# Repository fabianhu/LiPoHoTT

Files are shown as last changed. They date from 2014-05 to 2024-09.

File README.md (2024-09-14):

LiPoHoTT
========

2S to 6S LiPo monitor for HoTT telemetry.
(c) 2012-2014 Fabian Huslik

order PCBs here:
https://oshpark.com/shared_projects/f62OUvRq

Features:
Optocoupler for communication interface
2-6 Cells
2.54mm pitch connector XH or XT
emulates HoTT GAM
Calibration via full battery
Adjustable alarm levels (2)
External current monitoring possible

Future features:
2-14 in multi-chain-configuration
Configurable as HoTT GAM or EAM
Adjustable alarm delay
Bootloader for field update

This project includes hardware and firmware.

Software released under GPLv3.
Hardware "source code" = .brd & .sch realeased under GPLv3 as well.

Uses code from :

HoTT v4 telemetry for ArduCopter by Adam Majerczyk
printf library by Kustaa Nyholm / SpareTimeLabs
Interrupt UART library by Peter Fleury

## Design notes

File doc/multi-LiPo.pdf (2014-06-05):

... ?

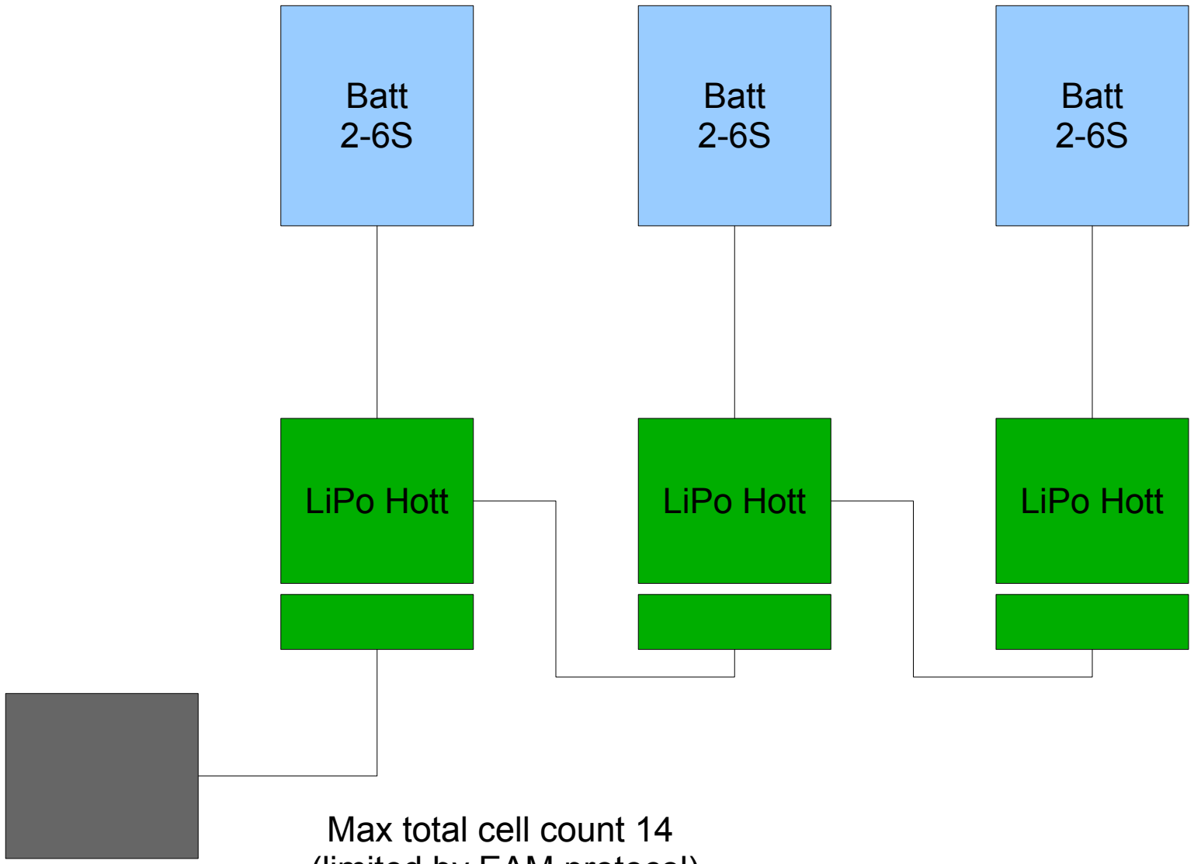
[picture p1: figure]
LiPo Hott; Batt 2-6S; Max total cell count 14

(limited by EAM protocol)

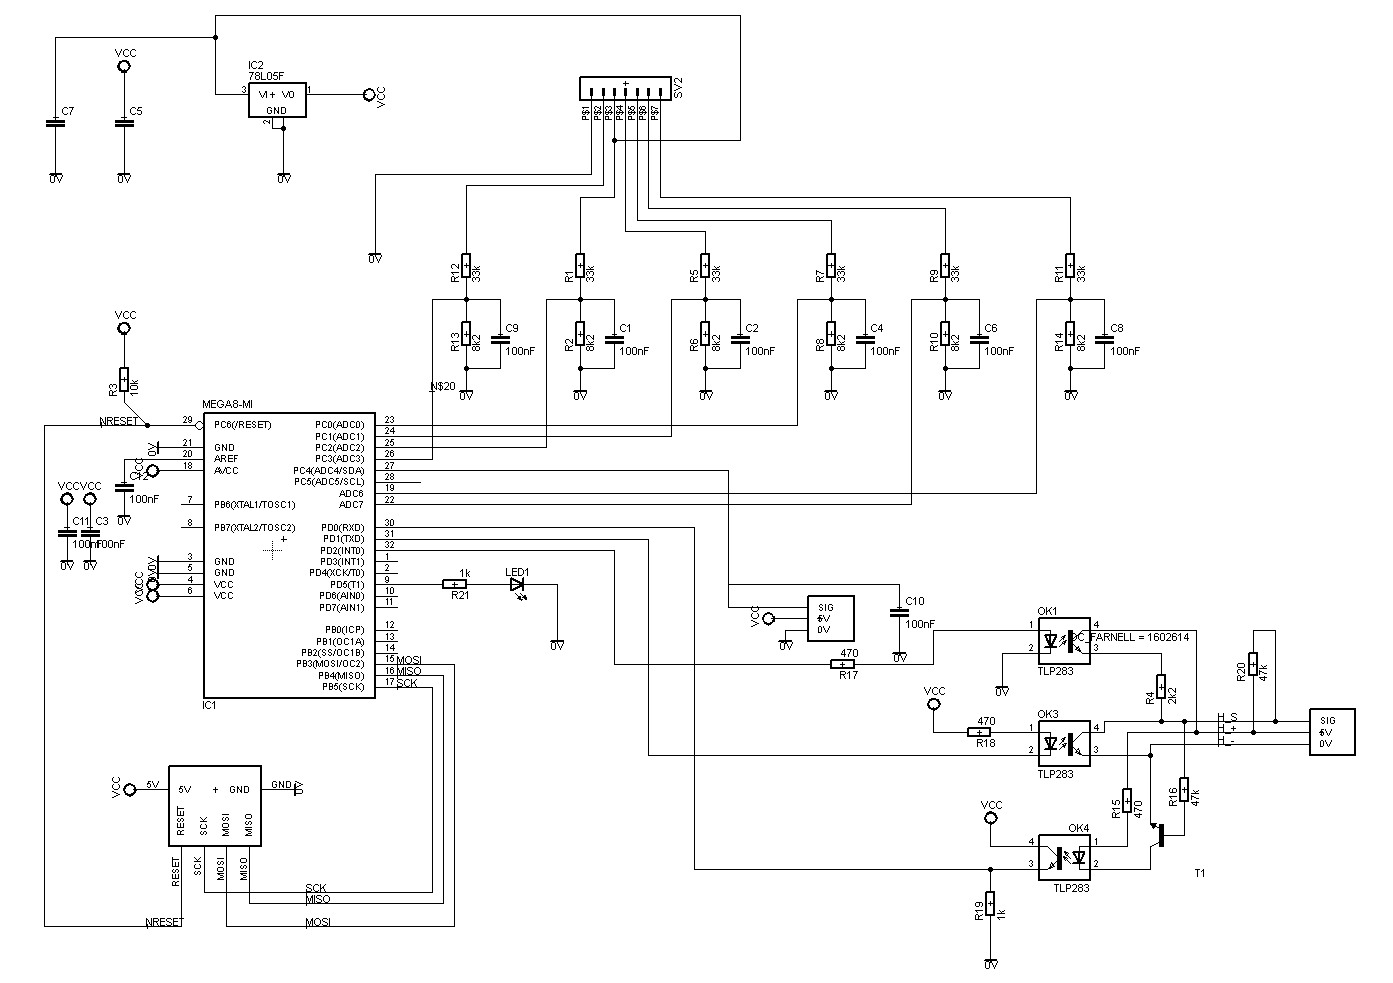
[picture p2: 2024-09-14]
doc/LiPoHott schematic.png

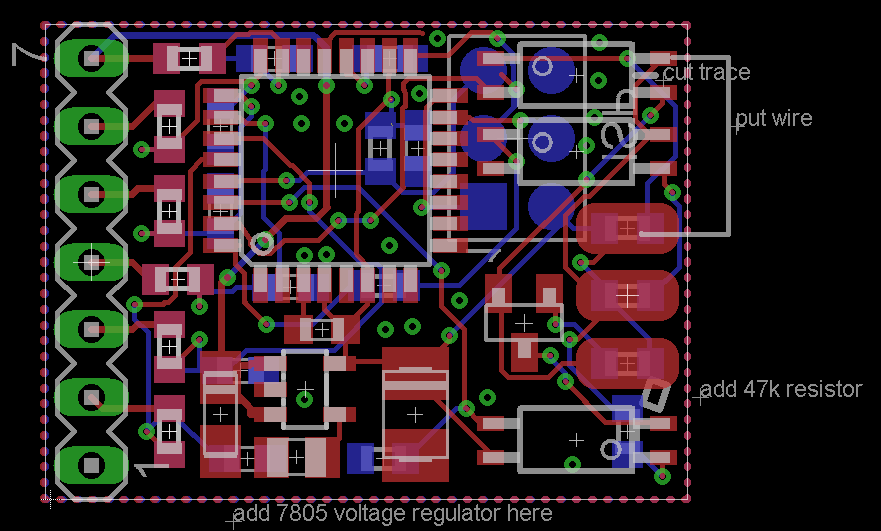
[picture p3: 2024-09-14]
doc/LiPoHoTT.png

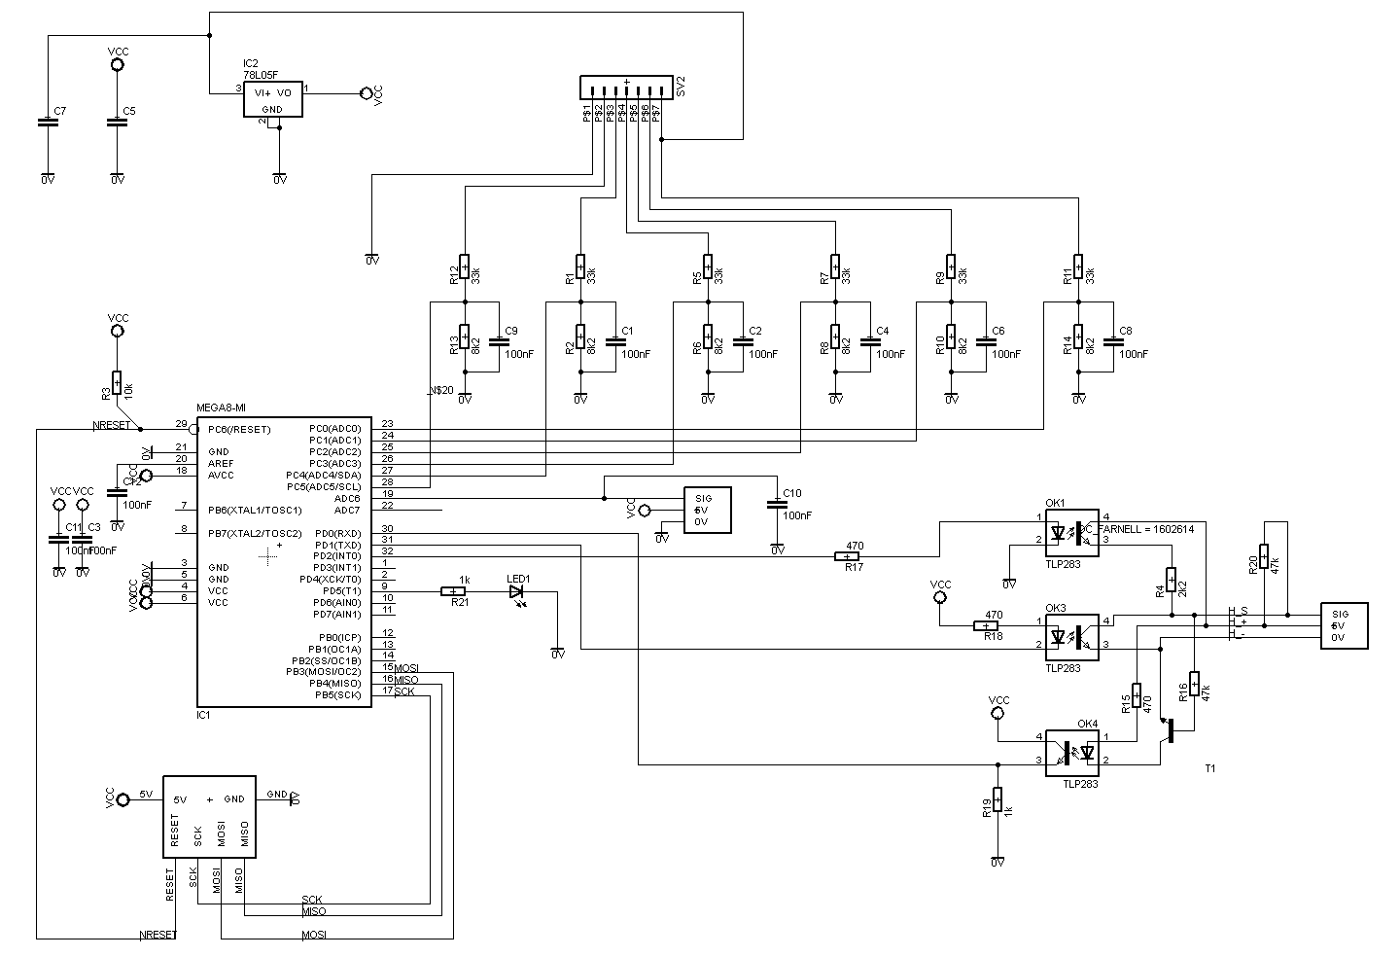
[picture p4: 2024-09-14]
doc/LiPoHott_kpl.png

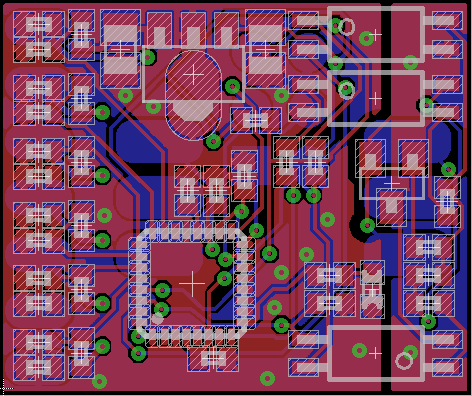
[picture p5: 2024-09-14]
doc/LiPoHoTT2.png

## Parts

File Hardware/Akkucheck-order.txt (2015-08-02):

Order list for D:/projekt/work/#Github/LiPoHoTT/Hardware/Akkucheck.sch
Exported from EAGLE with DesignLink

Anzahl	Value	Package	Ordercode	Hersteller	Herstellercode	Verfügbarkeit	Preis (ab)	Beschreibung
90	100nF	C0402	1867948	AVX	04023C104KAT2A	26032	0.0162	AVX - 04023C104KAT2A - KONDENSATOR, MLCC, X7R, 100NF, 25V, 0402
18	2u2	C0805	2320829	MULTICOMP	MC0805B225K250CT	21085	0.046	MULTICOMP - MC0805B225K250CT - KONDENSATOR, MLCC, X7R, 2.2UF, 25V, 0805
9	MEGA8-MI	MLF32	1715491	ATMEL	ATMEGA88PA-MU	1754	1.31	ATMEL - ATMEGA88PA-MU - MCU 8BIT, AVR, 8K FLASH, 32MLF
9	78L05F	SOT89	1467762	STMICROELECTRONICS	L78L05ABUTR	10209	0.142	STMICROELECTRONICS - L78L05ABUTR - SPANNUNGSREGLER,5V,SMD
18		3WIRE_CONN	unknown					
9		CHIPLED_0603	unknown					
27	TLP283	MINI-FLAT-4	1602614	AVAGO TECHNOLOGIES	ACPL-217-500E	23901	0.238	AVAGO TECHNOLOGIES - ACPL-217-500E - OPTOKOPPLER,TRANSISTOR O/P
54	33k	R0402	2331513	TE CONNECTIVITY	CRG0402F33K	21070	0.0027	TE CONNECTIVITY - CRG0402F33K - FESTWIDERSTAND, 33K, 1%, 0402
54	8k2	R0402	2331571	TE CONNECTIVITY	CRG0402F8K2	3991	0.0027	TE CONNECTIVITY - CRG0402F8K2 - FESTWIDERSTAND, 8K2, 1%, 0402
9	10k	R0402	1738864	VISHAY DRALORIC	CRCW040210K0FKEAHP	463687	0.011	VISHAY DRALORIC - CRCW040210K0FKEAHP - LEISTUNGSWIDERSTAND, 10K, 0.125W, 1%
9	2k2	R0402	2059231	PANASONIC ELECTRONIC COMPONENTS	ERJ2GEJ222X	7048	0.0020	PANASONIC ELECTRONIC COMPONENTS - ERJ2GEJ222X - WIDERSTAND, 0402, 2K2, 5%, 0.1W
27	470	R0402	2059203	PANASONIC ELECTRONIC COMPONENTS	ERJ2GEJ470X	12566	0.0021	PANASONIC ELECTRONIC COMPONENTS - ERJ2GEJ470X - WIDERSTAND, 0402, 47R, 5%, 0.1W
18	47k	R0402	2059246	PANASONIC ELECTRONIC COMPONENTS	ERJ2GEJ473X	10294	0.0020	PANASONIC ELECTRONIC COMPONENTS - ERJ2GEJ473X - WIDERSTAND, 0402, 47K, 5%, 0.1W
18	1k	R0402	2059225	PANASONIC ELECTRONIC COMPONENTS	ERJ2GEJ102X	23250	0.0020	PANASONIC ELECTRONIC COMPONENTS - ERJ2GEJ102X - WIDERSTAND, 0402, 1K, 5%, 0.1W
9		MA07-1_SMD	unknown					
9		SOT23-BEC	1081223	NXP	BC817,215	239246	0.0237	NXP - BC817,215 - TRANSISTOR, NPN, 45V, SOT-23
9	ISPSMD	ISP_SMD	unknown

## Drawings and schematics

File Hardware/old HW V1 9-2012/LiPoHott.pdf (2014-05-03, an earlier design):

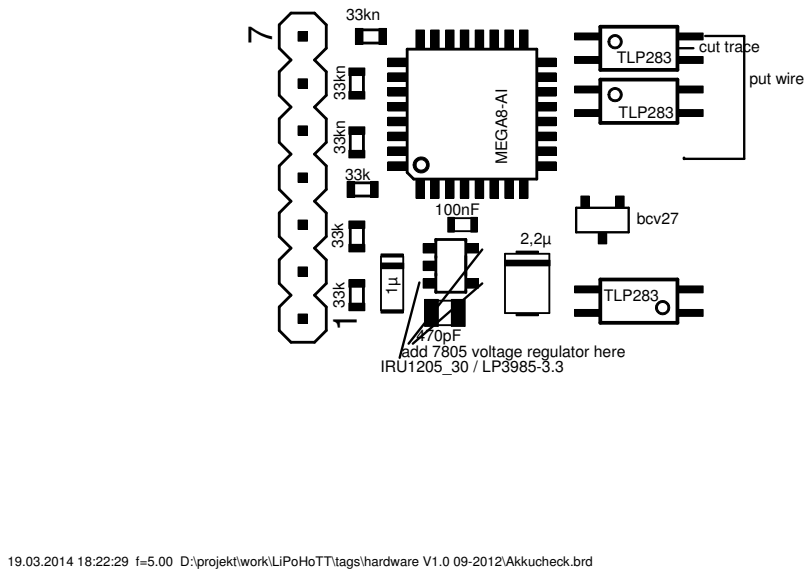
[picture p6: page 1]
7cut trace; put wire; add 7805 voltage regulator here; IRU1205_30 / LP3985-3.3; MEGA8-AI; TLP283; bcv27

19.03.2014 18:22:29 f=5.00 D:\projekt\work\LiPoHoTT\tags\hardware V1.0 09-2012\Akkucheck.brd

19.03.2014 18:23:15 f=5.00 mirrored D:\projekt\work\LiPoHoTT\tags\hardware V1.0 09-2012\Akkucheck.brd

1

# ISP

100nF

10k

10k

100nF

### 10k 100nF

10k
100nF

### 100nFn

## 10kn 10kn

### 100nFn

### 100nFn 10kn

2k2

470

33k

470

470

1k

100nF

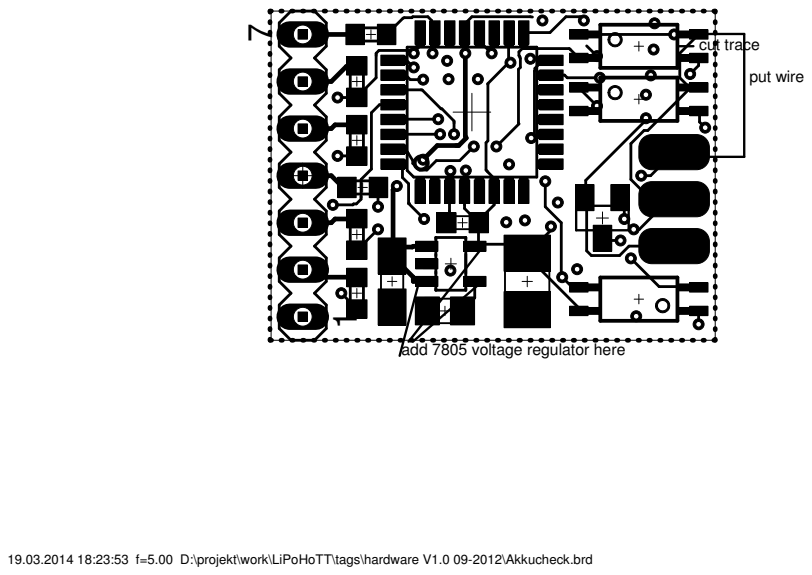
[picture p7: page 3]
7cut trace; put wire

add 7805 voltage regulator here

19.03.2014 18:23:53 f=5.00 D:\projekt\work\LiPoHoTT\tags\hardware V1.0 09-2012\Akkucheck.brd

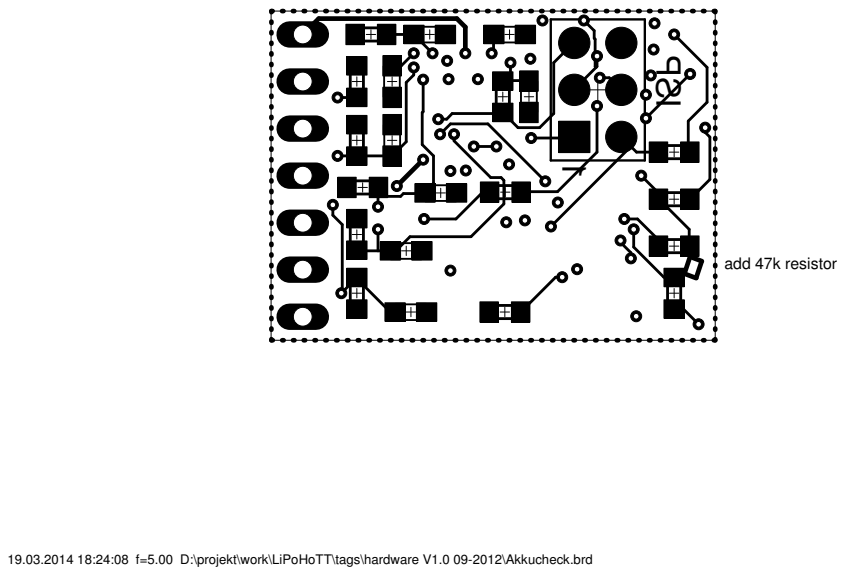
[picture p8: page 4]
add 47k resistor; ISP

19.03.2014 18:24:08 f=5.00 D:\projekt\work\LiPoHoTT\tags\hardware V1.0 09-2012\Akkucheck.brd

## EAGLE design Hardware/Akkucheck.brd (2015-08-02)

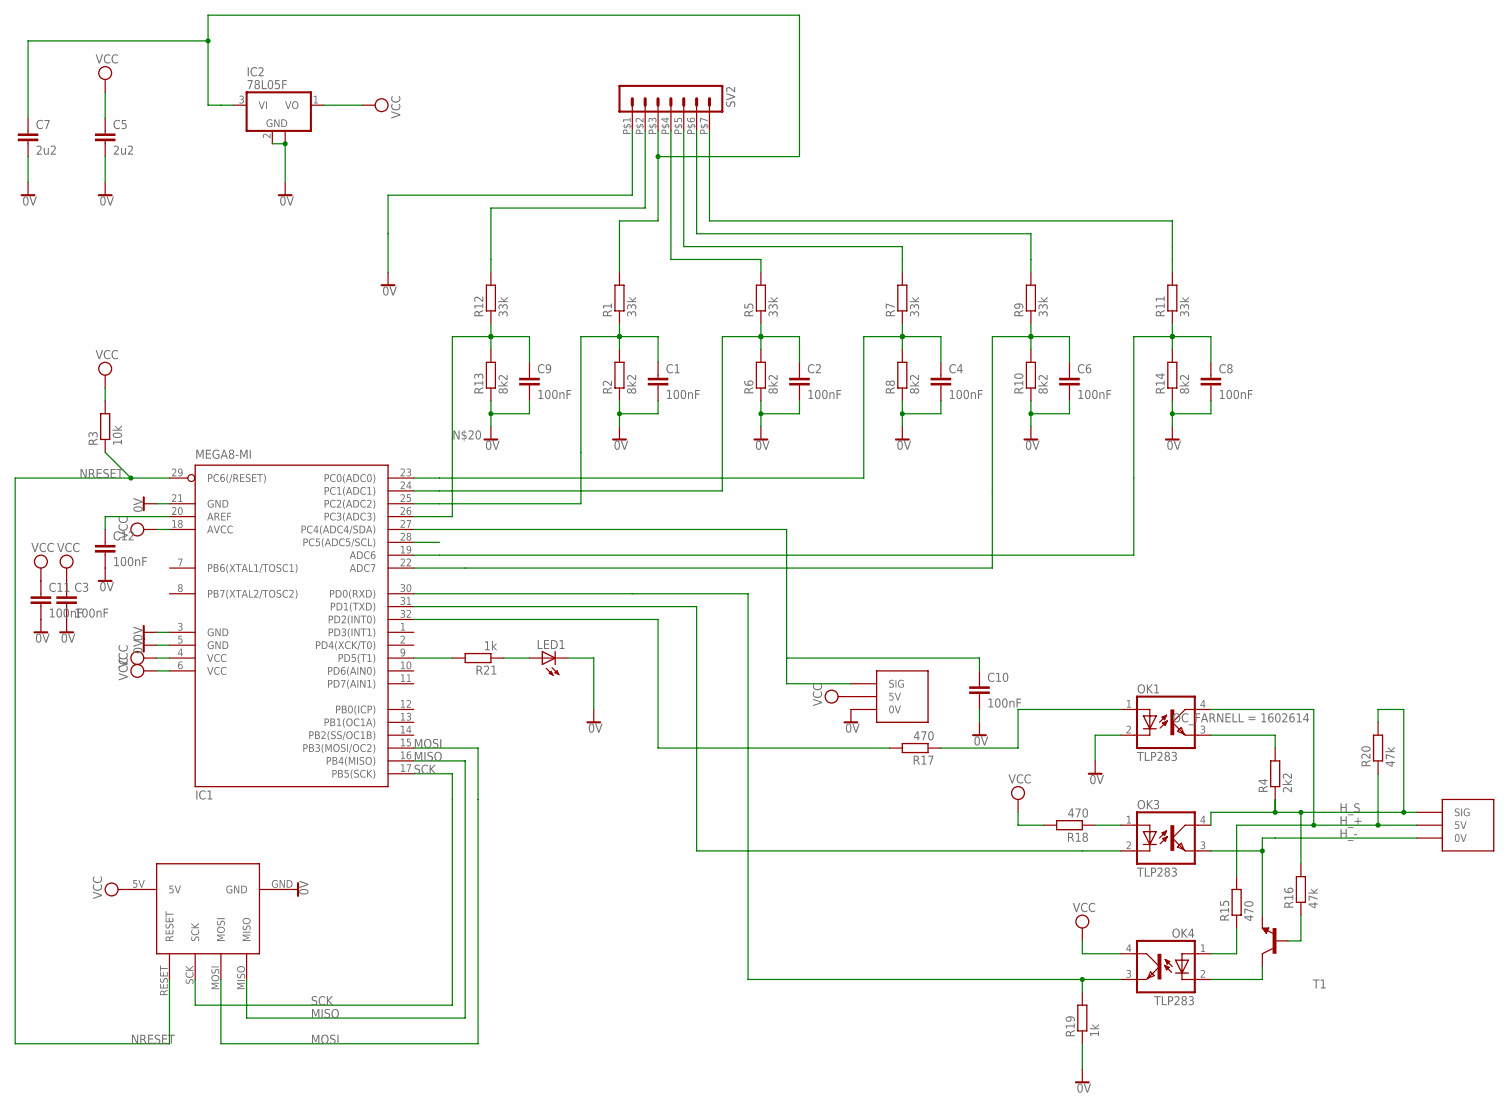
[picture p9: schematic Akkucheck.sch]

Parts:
C1, C2, C3, C4, C6, C8, C9, C10, C11, C12: 100nF; C0402; MPN 04023C104KAT2A
C5, C7: 2u2; C0805; MPN MC0805B225K250CT
IC1: MEGA8-MI; MLF32
IC2: 78L05F; SOT89; MPN L78L05ABUTR
IN1, IN3: 3-WIRE_CONNWIRE; 3WIRE_CONN
LED1: LEDCHIPLED_0603; CHIPLED_0603
OK1, OK3, OK4: TLP283; MINI-FLAT-4; MPN ACPL-217-500E
R1, R5, R7, R9, R11, R12: 33k; R0402; MPN CRG0402F33K
R2, R6, R8, R10, R13, R14: 8k2; R0402; MPN CRG0402F8K2
R3: 10k; R0402; MPN CRCW040210K0FKEAHP
R4: 2k2; R0402; MPN ERJ2GEJ222X
R15, R17, R18: 470; R0402; MPN ERJ2GEJ470X
R16, R20: 47k; R0402; MPN ERJ2GEJ473X
R19, R21: 1k; R0402; MPN ERJ2GEJ102X
SV2: MA07-1_SMD
T1: BC817-16-NPN-SOT23-BEC; SOT23-BEC; MPN BC817,215
U$1: ISPSMD; ISP_SMD

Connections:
0V: C1.2, C2.2, C3.2, C4.2, C5.2, C6.2, C7.2, C8.2, C9.2, C10.2, C11.2, C12.2, IC1.3 (GND), IC1.5 (GND), IC1.21 (GND), IC2.2 (GND), IC2.2@1 (GND), IN1.0V, LED1.C, OK1.2 (C), R2.1, R6.1, R8.1, R10.1, R13.1, R14.1, R19.1, SV2.P$1 (1), U$1.GND
H_+: IN3.5V, OK1.4 (COL), R15.2, R20.1
H_-: IN3.0V, OK3.3 (EMIT), T1.E
H_S: IN3.SIG, OK3.4 (COL), R4.1, R16.2, R20.2
MISO: IC1.16 (PB4(MISO)), U$1.MISO
MOSI: IC1.15 (PB3(MOSI/OC2)), U$1.MOSI
unnamed: R12.2, SV2.P$2 (2)
unnamed: C6.1, IC1.22 (ADC7), R9.1, R10.2
unnamed: R5.2, SV2.P$4 (4)
unnamed: R7.2, SV2.P$5 (5)
unnamed: R9.2, SV2.P$6 (6)
unnamed: C10.1, IC1.27 (PC4(ADC4/SDA)), IN1.SIG
unnamed: C7.1, IC2.3 (VI), R1.2, SV2.P$3 (3)
unnamed: C8.1, IC1.19 (ADC6), R11.1, R14.2
unnamed: LED1.A, R21.1
unnamed: IC1.9 (PD5(T1)), R21.2
unnamed: OK1.3 (EMIT), R4.2
unnamed: OK4.1 (A), R15.1
unnamed: OK4.2 (C), T1.C
unnamed: C1.1, IC1.25 (PC2(ADC2)), R1.1, R2.2
unnamed: C2.1, IC1.24 (PC1(ADC1)), R5.1, R6.2
unnamed: IC1.30 (PD0(RXD)), OK4.3 (EMIT), R19.2
unnamed: IC1.31 (PD1(TXD)), OK3.2 (C)
unnamed: C9.1, IC1.26 (PC3(ADC3)), R12.1, R13.2
unnamed: R16.1, T1.B
unnamed: OK3.1 (A), R18.1
unnamed: IC1.32 (PD2(INT0)), R17.2
unnamed: OK1.1 (A), R17.1
unnamed: C12.1, IC1.20 (AREF)
unnamed: R11.2, SV2.P$7 (7)
unnamed: C4.1, IC1.23 (PC0(ADC0)), R7.1, R8.2
NRESET: IC1.29 (PC6(/RESET)), R3.1, U$1.RESET
SCK: IC1.17 (PB5(SCK)), U$1.SCK
VCC: C3.1, C5.1, C11.1, IC1.4 (VCC), IC1.6 (VCC), IC1.18 (AVCC), IC2.1 (VO), IN1.5V, OK4.4 (COL), R3.2, R18.2, U$1.5V

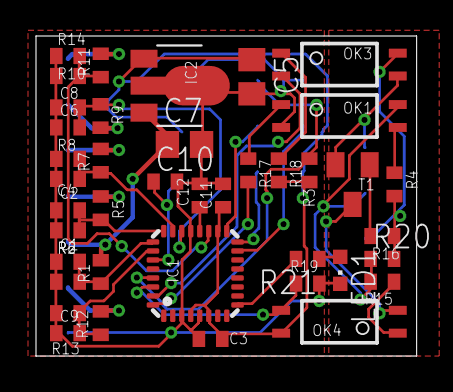
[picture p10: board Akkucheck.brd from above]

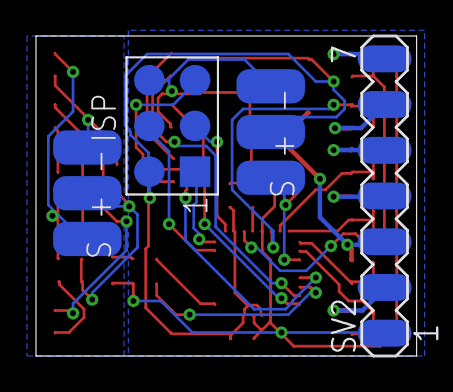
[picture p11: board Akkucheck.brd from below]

Board: 2 copper layers, 21.1 x 17.8 mm, 44 parts (4 on the bottom side), 34 nets.

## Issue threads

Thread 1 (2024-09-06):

Project Home Page

seanpoulter, 2024-09-06:
Hi Fabian,

I've been looking around for a 6S voltage sensor and found your build. The home page at https://www.huslik-elektronik.de/cms/embedded-hardware/31-lipohott is down. Would you be able to share those docs with me? I'm happy to open a PR to the repo in Markdown format.

Thanks and all the best from Ottawa, Canada. 🇨🇦

PS: That Tesla API is a really neat project!

fabianhu, 2024-09-14:
Hi Sean,
I just looked into my backups and put all files into the doc folder.
I would recommend, to import the Eagle files into Kicad.
The firmware could be built with the legacy AVR Studio.
I'm sure, there is a ton, that should be done differently now.

Closed 2024-09-14.

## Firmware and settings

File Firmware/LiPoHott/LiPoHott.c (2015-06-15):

/*
	LiPoHott.c
	
	Created: 06.09.2012 22:56:32
	Author: Fabian Huslik
 
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
 ATTENTION:
 COMPILE WITH WINAVR 20100110
 
 TODO:
 - Kalibrierung checken
 - Strom-Messung
 - mAh-Zähler
 
 Fuses:
 BOOTSZ = 1024W_0C00
 BOOTRST = [ ]
 RSTDISBL = [ ]
 DWEN = [ ]
 SPIEN = [X]
 WDTON = [ ]
 EESAVE = [ ]
 BODLEVEL = 4V3
 CKDIV8 = [X]
 CKOUT = [ ]
 SUT_CKSEL = INTRCOSC_8MHZ_6CK_14CK_65MS

 EXTENDED = 0xF9 (valid)
 HIGH = 0xDC (valid)
 LOW = 0x62 (valid)

 
 
  */ 

#ifdef F_CPU
#if F_CPU != 8000000
	#error "fcpu"
#endif
#else
	#define F_CPU 8000000
#endif

#include <avr/io.h>
#include <util/delay.h>
#include "uart.h"
#include "hottV4.h"
#include "LiPoHott.h"
#include <avr/eeprom.h>
#include <avr/interrupt.h>
#include "printf.h"
#include <math.h>


uint16_t adc_get_filter_channel(uint8_t ); // reads the adc x times and filters.
uint16_t a2dConvert10bit(uint8_t ch);
void getADC(void);
uint16_t ADC_to_mV(uint16_t val);
void init_Par(void);
void timing_init(void);

extern uint32_t lastComm;

static volatile uint32_t GlobalTimer_us; // the global timer, incremented by ISR every 100 us

data_t myData;
par_t myPar;


int main(void)
{
	//initialization
	DDRB  = 0; 
	PORTB = 0;
	DDRC  = 0;
	PORTC = 0;
	DDRD  = (1<<PD1)|(1<<PD2)|(1<<PD5);// rx/tx switch + LED
	PORTD = (1<<PD1);// tx high idle!
	
	// crank up the CPU to 8MHz
	while(CLKPR != 0) 
	{
		asm("nop");	
		CLKPR = 1<<7;// will not work without optimisation !!!!
		CLKPR = 0;

	}

	ADCSRA = 0b10000110; //ADEN ADSC ADATE ADIF ADIE ADPS2 ADPS1 ADPS0 // 125kHz adc-clock
	DIDR0 = 0b00111111;

	timing_init();

	init_Par();

	// init USART for 19200 baud
	uart_init(UART_BAUD_SELECT(19200,F_CPU));
	asm("sei");
    while(1)
    {
        
		getADC(); // calls Hott between conversions
		
		if (GetTime() - lastComm > 1000000)
		PORTD |= (1<<PD5); // toggle LED
    }
}

#define MEASURES 64 // max 64! // use 2^n for shift-divide.
uint16_t adc_get_filter_channel(uint8_t c) // takes about 6,4ms
{
    uint16_t a;	

	
	uint8_t z;
	
	a=0;
	for (z =0;z<MEASURES;z++)
	{
		a+=a2dConvert10bit(c); // takes 100 us
		
		uint32_t t = GetTime();
		_hott_serial_scheduler(t); // HOTT here, as timing allows it only here.
		
		
	}
	
	return a;///MEASURES; 
}

uint32_t GetTime(void)
{
	uint32_t t;
	cli();
	t= GlobalTimer_us;
	sei();
	return t;
}


//! Perform a 10-bit conversion
// starts conversion, waits until conversion is done, and returns result
uint16_t a2dConvert10bit(uint8_t ch) // ch 14 gets 1.1V bandgap reference fixme // takes about 0.1ms
{
	
	ADMUX = 0b01000000 | (ch & 0b00001111);
	
	ADCSRA |= (1<< ADSC) | (1<<ADIF);	

	while( !(ADCSRA & (1<<ADIF)) )
	{
		ch++; // dummmy
	}		// wait until conversion complete

	// CAUTION: MUST READ ADCL BEFORE ADCH!!!
	return ADC;//(ADCL) | ((ADCH)<<8);	// read ADC (full 10 bits);
}

#define limit(v,l,u) (((v)<(l))?(l):(((v)>(u))?(u):(v)))

int32_t propscale(int32_t _value, int32_t _minin, int32_t _maxin, int32_t _minout, int32_t _maxout)
{
	int32_t rangedvalue;
	int32_t inrange = _maxin-_minin;
	int32_t outrange = _maxout-_minout;
	if(inrange== 0) return 0; // divide by zero protection
	
	_value = limit(_value,_minin,_maxin); // do not extrapolate
	
	rangedvalue = (_value-_minin)*outrange/inrange;

	return rangedvalue + _minout;
}

volatile int32_t tmp;

int32_t ScaleCurrmA(int32_t _raw)
{
	/*
	5V = 1024 bits.
	2,5V = 512 bits
	1V = 204.8 bits.

	for ACS750xCA-050
	40 mV / A
	8,192 bit / A
	0,1220703125 A/bit
	122,070 mA/bit
	
	(+-50A = 0,5V / 4,5V )
	*/
	
	tmp = _raw/MEASURES;
	asm("nop");
	tmp= (int32_t)tmp - (int32_t)myPar.zeroBits; // center volt
	tmp = tmp * (int32_t)122; // 
	tmp = abs(tmp); // fixme return only positives
	
	return tmp;
}

void getADC(void)
{
	uint16_t raw[6];

	for (uint8_t i =0;i<MEASCELLCOUNT;i++)
	{
		raw[i] = ADC_to_mV(adc_get_filter_channel(5-i));
	}
	
	myData.CurrentmA = abs(ScaleCurrmA(adc_get_filter_channel(6)));
	
	if(myData.CurrentmA !=0)
	{
		asm("nop");
	}
	
	uint32_t _now = GetTime()/100;
	
	static uint32_t oldCapTime=0;
	uint32_t CapDiffTime = _now - oldCapTime;
	oldCapTime = _now;
	myData.CapamAs += ((CapDiffTime)*(myData.CurrentmA))/10000;
	
		
	myData.UCell[0] = raw[0]+propscale(raw[0],0,4200-myPar.Cal[0],0,myPar.Cal[0]);

	uint16_t batt=myData.UCell[0];
	for (uint8_t i =1;i<myPar.cells;i++) // calibration proportional to raw value?
	{
		int16_t v = raw[i]-raw[i-1];
		
		myData.UCell[i] = v+propscale(v,0,4200-myPar.Cal[i],0,myPar.Cal[i]);//   myPar.Cal[i];
		batt += myData.UCell[i];
	}		
	myData.UBatt = batt;
	
	// some calculations
	uint16_t Umin=4200;
	uint8_t nmin = 0;
	uint8_t almL = 0;
	uint8_t almH = 0;
	for (uint8_t i =0;i<myPar.cells;i++)
	{
		if(myData.UCell[i]<Umin && myData.UCell[i] > MINCELLVOLTCALC)
		{
			Umin = myData.UCell[i];
			nmin = i;
		}
		if(myData.UCell[i]<myPar.limitL && myData.UCell[i] > MINCELLVOLTCALC)
		{
			almL |= 1<<i;
		}
		if(myData.UCell[i]<myPar.limitH && myData.UCell[i] > MINCELLVOLTCALC)
		{
			almH |= 1<<i;
		}
	}
	myData.almL = almL;
	myData.almH = almH;

	myData.UminCellV = Umin;
	myData.UminCellNum = nmin+1;

	/*int16_t level = Umin - myPar.limitL;
	int16_t total = 4230 - myPar.limitL;
	int16_t res = level*100L / total;*/
	myData.fill = propscale(Umin,myPar.limitH,4200,0,100);//  (uint8_t)res;
	
}



#define MAXADC 1023*64


uint16_t ADC_to_mV(uint16_t val)
{
	uint32_t temp;
	temp = val * (uint32_t)UINMAX;
	return (uint16_t)(temp>>16);// / MAXADC; == divide by 1024*64
}

void init_Par(void)
{
	
	
	eeprom_read_block((uint8_t*)&myPar,(void*)1,sizeof(par_t));
	
	if(myPar.Cal[0] == 0xffff)
	{
		myPar.Cal[0]= 0;
		myPar.Cal[1]= 0;
		myPar.Cal[2]= 0;
		myPar.Cal[3]= 0;
		myPar.Cal[4]= 0;
		myPar.Cal[5]= 0;
	}
	if(myPar.limitL > 4200 || myPar.limitL < 2300)
		myPar.limitL = 3200;
	if(myPar.limitH > 4200 || myPar.limitH < 2300)
		myPar.limitH = 3200;	
	if(myPar.cells > MEASCELLCOUNT || myPar.cells < 1)
		myPar.cells = MEASCELLCOUNT;
	if(myPar.zeroBits >600 || myPar.zeroBits <400) 
		myPar.zeroBits = 512;
	
	
}

void SafePars(void)
{
	static uint8_t safecount=0;
	safecount++;
	if(safecount >5)	return; // prevent numerous safes.
	eeprom_update_block((uint8_t*)&myPar,(void*)1,sizeof(par_t));
}

void CalibrateZeroCurrent(void)
{
	myPar.zeroBits = adc_get_filter_channel(6)/MEASURES;
}


void Calibrate(void)
{
	// measure the raw value
	uint16_t raw[MEASCELLCOUNT];

	for (uint8_t i =0;i<MEASCELLCOUNT;i++)
	{
		raw[i] = ADC_to_mV(adc_get_filter_channel(5-i));
	}
	myData.UCell[0] = raw[0];
	for (uint8_t i =1;i<MEASCELLCOUNT-1;i++)
	{
		myData.UCell[i] = raw[i]-raw[i-1];
	}
	
	
	for (uint8_t i =0;i<MEASCELLCOUNT;i++)
	{
		myPar.Cal[i] = CALEXPECTEDmV - myData.UCell[i];
		if(abs(myPar.Cal[i]) > 300) // deny calibration if too far off.
			myPar.Cal[i] = 0;
	}
	// 
}

#define OS_ScheduleISR 			TIMER0_COMPA_vect // Interrupt Vector used for OS-tick generation (check out CustomOS_ISRCode if you want to add isr code)
#define OS_ALLOWSCHEDULING 		TIMSK0 |= (1<<OCIE0A);	// turn Timer Interrupt ON
#define OS_PREVENTSCHEDULING 	TIMSK0 &= ~(1<<OCIE0A); // turn Timer Interrupt OFF


void timing_init(void)
{
	GlobalTimer_us = 0;
	
	TCCR0A = 0;
//	TCCR0B = 0b00000011; // 125kHz Clock @ 8MHz,
	TCCR0B = 0b00000010; // 1000kHz Clock @ 8MHz,
	
	OCR0B = 100; //which overflows after 100 cycles, which gives the desired 0.1ms increment
	TIMSK0 = (1<<OCIE0B); // ISR for OS
	
}


ISR(TIMER0_COMPB_vect)
{
	TCNT0 =0;  // reset the timer on ISR to have correct timing
	GlobalTimer_us+=100;
}


void HandleHott( unsigned char addr, uint8_t* txtptr )
{
	static uint8_t line=0;
	static uint8_t edit=0;
	
	
	// key handling
	int8_t dlt=0;
	switch (addr&0x0f) // low nibble
	{
		case HOTT_TEXT_MODE_IDLE:
		// do nothing here, as this means that no button is pressed.
		break;
		case HOTT_TEXT_MODE_RIGHT:
		if(edit==1)
		dlt=1;
		else
		break;
		case HOTT_TEXT_MODE_UP:
		if(edit==0 && line>0)
		line--;
		break;
		case HOTT_TEXT_MODE_LEFT:
		if(edit==1)
		dlt=-1;
		else
		break;
		case HOTT_TEXT_MODE_DOWN:
		if(edit==0 && line<5)
		line++;
		break;
		case HOTT_TEXT_MODE_SET:
		if(line==0 || line == 1 || line == 2)
		{
			edit = (edit==0)?1:0;
		}
		if(line==3)
		{
			// calibrate
			Calibrate();
			line =0;
		}
		if(line==4)
		{
			// calibrate Zero Current
			CalibrateZeroCurrent();
			line =0;
		}
		if(line==5)
		{
			// safe to eeprom
			SafePars();
			line =0;
		}
		break;
		default:
		break;
	}
	if(dlt != 0)
	{
		int16_t t;
		switch(line)
		{
			case 0: // limit
			t = myPar.limitL+dlt*50;
			if (t>2500 && t<4200)
			{
				myPar.limitL = t;
			}
			
			break;
			case 1: // limit
			t = myPar.limitH+dlt*50;
			if (t>2500 && t<4200)
			{
				myPar.limitH = t;
			}
			
			break;

			case 2: // cellcount
			t = myPar.cells+dlt;
			if (t>0 && t<=MEASCELLCOUNT)
			{
				myPar.cells = t;
			}
			
			break;
			case 3:	// calibrate
			
			break;
			case 4:	// calibrate Zero Current
			
			break;
			case 5:	// safe
			
			break;
			default:
			break;
			
		}
	}
	
	// text building
	sprintf(txtptr,       "  LiPoHott V1.2      ");
	hott_invert_chars(txtptr,21);
	sprintf(&txtptr[1*21],"  Limit Low: %dmV ",myPar.limitL);
	sprintf(&txtptr[2*21],"  Limit Hi: %dmV ",myPar.limitH);
	sprintf(&txtptr[3*21],"  Cells: %d     ",myPar.cells);
	sprintf(&txtptr[4*21],"  Calibrate to %dmV",CALEXPECTEDmV);
	sprintf(&txtptr[5*21],"  Set Current to Zero ");
	sprintf(&txtptr[6*21],"  Safe_to_flash ");
	//sprintf(&txtptr[6*21],"---------------------");
	//1:1234 2:1234 3:1234
	sprintf(&txtptr[7*21]," (c) huslik.net 2015 ");
	hott_invert_chars(&txtptr[7*21],21);
	//sprintf(&txtptr[7*21],"t:%d",timer_ms);
	//sprintf(&txtptr[7*21],"1:%d 2:%d 3:%d",myData.UCell[0],myData.UCell[1],myData.UCell[2]);
	//sprintf(&txtptr[7*21],"line: %d add:%d ",line,addr&0x0f); // do not use the last char!!!
	//sprintf(&txtptr[7*21],"4:%d 5:%d 6:%d",myData.UCell[3],myData.UCell[4],myData.UCell[5]); // do not use the last char!!!
	
	// set '>'
	txtptr[(line+1)*21]= (edit ==0)?'>':'*';
	
	// clean up zeroes
	for(int i = 0;i< sizeof(HOTT_TEXTMODE_MSG_t);i++)
	{
		if(txtptr[i] == 0)
		txtptr[i] = ' ';
	}
	
	PORTD ^= (1<<PD5); // toggle LED
	lastComm = GetTime();
}

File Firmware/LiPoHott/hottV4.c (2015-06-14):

/*
 * hottV4.c
 *
 * Created: 06.09.2012 23:14:14
 * split the original arduino .pde to .c and .h
 * see header file for original license
 
 Timing stuff:
 Measured from GAM / Voltage Module:
 wait 6.5 ms before starting to answer;
 leave 2 ms between bytes on answer.
 
 */ 


#include <avr/io.h>
//#include <string.h>
#include "hottV4.h"
#include "uart.h"
#include "LiPoHott.h"
#include <avr/interrupt.h>


#define _HOTT_PORT_read uart_getc
#define _HOTT_PORT_write uart_putc
#define _HOTT_PORT_available uart_data
#define _HOTT_PORT_flush uart_flush

extern data_t myData;
extern par_t myPar;

static uint8_t _hott_telemetry_is_sending = false;
//static uint8_t _hott_telemetry_sendig_msgs_id = 0;

//HoTT serial buffer
#ifdef HOTT_SIM_TEXTMODE
static uint8_t _hott_serial_buffer_textmode[172+1]; // there has to be one more for the tailing 0.
#endif
static uint8_t _hott_serial_buffer[44];

// HoTT serial send buffer pointer
static uint8_t *_hott_msg_ptr = 0;
// Len of HoTT serial buffer
static int _hott_msg_len = 0;

uint32_t lastComm = 0;


void _hott_enable_transmitter(void) {
  //enables serial transmitter, disables receiver
	UCSR0B = (1<<TXEN0);

	PORTD |= _BV(PD2); // enable pull-up 
	// PORTD |= _BV(PD1); // high idle / no pull-down.
}

void _hott_enable_receiver(void) {
   //enables serial receiver, disables transmitter
	UCSR0B = _BV(RXCIE0)|(1<<RXEN0);
	PORTD &= ~_BV(PD2); // disable pull-up
	PORTD |= _BV(PD1); // high idle / no pull-down.
}



void _hott_send_telemetry_data(void);
void _hott_check_serial_data(uint32_t tnow);
void _hott_send_msg_text(uint8_t *buffer, int len);
void _hott_send_msg(uint8_t *buffer, int len);
void _hott_update_gam_msg(void);


//*****************************************************************************
/*
  Called periodically (?1ms) by timer scheduler
  
  @param tnow  timestamp in uSecond
*/
void _hott_serial_scheduler(uint32_t tnow) {
	static uint32_t _hott_serial_timer;
   _hott_check_serial_data(tnow);	// Check for data request
  if(_hott_msg_ptr == 0) return;   //no data to send
  if(_hott_telemetry_is_sending) {
    //we are sending already, wait for a delay of 2ms between data uint8_ts
    if(tnow - _hott_serial_timer < 3000)  //delay ca. 3,5 mS. 19200 baud = 520uS / uint8_t + 3ms required delay
    										// Graupner Specs claims here 2ms but in reality it's 3ms, they using 3ms too...
      return;
  } else {
  	//new data request
  	tnow = GetTime(); //correct the 5ms  delay in _hott_check_serial_data()...
 
  }
  _hott_send_telemetry_data();
  _hott_serial_timer = tnow;
}

/*
  Transmitts a HoTT message
*/
void _hott_send_telemetry_data() {
  static int msg_crc = 0;
  if(!_hott_telemetry_is_sending) {
  	// new message to send
    _hott_telemetry_is_sending = true;
    _hott_enable_transmitter();  //switch to transmit mode  
  }

  //send data
  if(_hott_msg_len == 0) {
    //all data send
    _hott_msg_ptr = 0;
    _hott_telemetry_is_sending = false;
    msg_crc = 0;
    _hott_enable_receiver();
    _HOTT_PORT_flush();
  } else {
    --_hott_msg_len;
    if(_hott_msg_len != 0) {
       	msg_crc += *_hott_msg_ptr; 
	    _HOTT_PORT_write(*_hott_msg_ptr++);
    } else {
    	//last uint8_t, send crc
	    _HOTT_PORT_write((uint8_t)msg_crc);
    } 
  }
}

/*
  Onetime setup for HoTT
*/
void _hott_setup() {
  //_HOTT_PORT_begin(19200);
  _hott_enable_receiver();
  //timer_scheduler.register_process(_hott_serial_scheduler);
}



/*
  Check for a valid HoTT requests on serial bus
*/

void _hott_check_serial_data(uint32_t tnow) {
	static uint32_t _hott_serial_request_timer = 0;
	if(_hott_telemetry_is_sending == true) return;
    if(_HOTT_PORT_available() > 1) {
      if(_HOTT_PORT_available() == 2) {
        if(_hott_serial_request_timer == 0) {
        	//new request, check required
        	_hott_serial_request_timer = tnow;	//save timestamp
        	return;
        } else {
        	if(tnow - _hott_serial_request_timer < 6500)	//wait ca. 5ms (Voltage module waits 6.5m)
        		return;
        	_hott_serial_request_timer = 0;	//clean timer
        }
        // we never reach this point if there is additionally data on bus, so is has to be valid request
        unsigned char c = _HOTT_PORT_read();
       static  unsigned char addr;//; = _HOTT_PORT_read();
	   addr = _HOTT_PORT_read();
        //ok, we have a valid request, check for address
		
  	    uint8_t tmp = (addr >> 4);  // Sensor type
        switch(c) {
//*****************************************************************************
#ifdef HOTT_SIM_TEXTMODE
          case HOTT_TEXT_MODE_REQUEST_ID:
           //Text mode
             {
               
               
               
             	HOTT_TEXTMODE_MSG_t	*hott_txt_msg =	(HOTT_TEXTMODE_MSG_t *)&_hott_serial_buffer_textmode[0];
				memset(hott_txt_msg, ' ', sizeof(HOTT_TEXTMODE_MSG_t));
				hott_txt_msg->start_uint8_t = 0x7b;
				hott_txt_msg->stop_uint8_t = 0x7d;
				hott_txt_msg->fill1 = 0xD0; 
				hott_txt_msg->warning_beeps = 0; // just prevent beeping
                
				//hott_txt_msg = HOTT_Clear_Text_Screen(hott_txt_msg);

				

#ifdef HOTT_SIM_GPS_SENSOR
             if(tmp == (HOTT_TELEMETRY_GPS_SENSOR_ID & 0x0f))    hott_txt_msg = HOTT_PrintWord(3*21, "GPS sensor module",0, hott_txt_msg);
#endif
#ifdef HOTT_SIM_EAM_SENSOR
             if(tmp == (HOTT_TELEMETRY_EAM_SENSOR_ID & 0x0f))    hott_txt_msg = HOTT_HandleTextMode(addr, hott_txt_msg);
#endif
#ifdef HOTT_SIM_VARIO_SENSOR
             if(tmp == (HOTT_TELEMETRY_VARIO_SENSOR_ID & 0x0f))  hott_txt_msg = HOTT_PrintWord(3*21, "Vario sensor module",0, hott_txt_msg);
#endif
#ifdef HOTT_SIM_GAM_SENSOR
             if(tmp == (HOTT_TELEMETRY_GAM_SENSOR_ID & 0x0f))    
			 {
				HandleHott(addr, &hott_txt_msg->msg_txt);
				hott_txt_msg->stop_uint8_t = 0x7d;
				_hott_send_msg_text(_hott_serial_buffer_textmode, sizeof(HOTT_TEXTMODE_MSG_t));

			 }
			 else
			 {
				 // this question was for someone else
			 }
#endif           
		}
#endif
           break;
//*****************************************************************************
          case HOTT_BINARY_MODE_REQUEST_ID:
#ifdef HOTT_SIM_GPS_SENSOR
			//GPS module binary mode
            if(addr == HOTT_TELEMETRY_GPS_SENSOR_ID) {
//            Serial.printf("\n%ld: REQ_GPS",micros() / 1000);
			 _hott_update_gps_msg();
             _hott_send_msg(_hott_serial_buffer, sizeof(struct HOTT_GPS_MSG));
             break;
            }
#endif
#ifdef HOTT_SIM_EAM_SENSOR
            if(addr == HOTT_TELEMETRY_EAM_SENSOR_ID) {
//            Serial.printf("\n%ld: REQ_EAM",micros() / 1000);
			  _hott_update_eam_msg();
		      _hott_send_msg(_hott_serial_buffer, sizeof(struct HOTT_EAM_MSG));
              break;
		    }
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

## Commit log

2014-05-03 added all files
    [Akkucheck.brd, Akkucheck.dsn, Akkucheck.sch]
2014-06-05 updated hardware+ - changed extension pin - out supply to cell 2
    [Akkucheck.brd, Akkucheck.sch]
2015-06-14 optimized for production at OSHpark
    [Akkucheck - OSH Park.brd, Akkucheck.dsn]
2015-06-14 optimized timer stuff
2015-06-15 add compiler requirement as comment
    With the new compiler the text mode does not work.
    [LiPoHott.c]
2015-08-02 updated BOM
    [Akkucheck.brd, Akkucheck.sch]

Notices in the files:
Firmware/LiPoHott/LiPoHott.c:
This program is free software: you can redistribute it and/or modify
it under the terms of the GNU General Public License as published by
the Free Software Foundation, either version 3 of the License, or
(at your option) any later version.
